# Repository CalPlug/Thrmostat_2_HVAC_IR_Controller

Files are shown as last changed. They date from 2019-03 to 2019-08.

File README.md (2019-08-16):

# ThermostatControl
Jigar Hira

Navid Bazmoon

Code to interface the NEST thermostat with ESP32

Utilizes the RMT ESP32 library to send IR signals controlling a portable AC unit.

## IR Transmission
ESP32 has built-in hardware for handling IR Codes.
The RMT library feeds the hardware two signals:

1)	Data signal which represents the 0 and 1 bits
2)	Carrier frequency square wave

The hardware in the ESP32 modulates the data signal using the square wave to produce the IR signal (more information can be found here: https://docs.espressif.com/projects/esp-idf/en/latest/api-reference/peripherals/rmt.html).

## NEST signals
In order to interface with the NEST smart thermostat, we use a simple circuit to convert 24VAC thermostat signals to lower voltage DC signals.

This allows us to use the GPIO pins on the ESP32 to detect what the NEST has turned on or off.

### NOTE:
This project is still in development

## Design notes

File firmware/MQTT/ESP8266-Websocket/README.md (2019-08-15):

## Modified by Navid Bazmoon - University of California, Irvine

## Changes were made for compatibility with ESP32

The file named MD5.cpp is modified and renamed to MD5ALT.cpp

Also the following changes were made in the above mentioned file:

MD5Init modified to MD5InitALT
MD5Update modified to MD5UpdateALT
MD5Final modified to MD5FinalALT

The file named MD5.h is modified and renamed to MD5ALT.cpp

Also the following changes were made in the above mentioned file:

MD5Init modified to MD5InitALT
MD5Update modified to MD5UpdateALT
MD5Final modified to MD5FinalALT

## End of Comments added by NB

## Websocket Client and Server for ESP-8266

This is a simple library that implements a Websocket client and server running on an ESP-8266.

### Getting started

The example WebSocketServer.html file should be served from any web server you have access to. Remember to change the  URL in it to your Arduino. The examples are based on using a WiFly wireless card to connect. If you're using ethernet instead you'll need to swap out the client class.

Install the library to "libraries" folder in your Arduino sketchbook folder. For example, on a mac that's `~/Documents/Arduino/libraries`.

Try the examples to ensure that things work.

Start playing with your own code!

### Notes
Inside of the WebSocketServer class there is a compiler directive to turn on support for the older "Hixie76" standard. If you don't need it, leave it off as it greatly increases the memory required.

Because of limitations of the current Arduino platform (Uno at the time of this writing), this library does not support messages larger than 65535 characters. In addition, this library only supports single-frame text frames. It currently does not recognize continuation frames, binary frames, or ping/pong frames.

### Credits
Thank you to github user ejeklint for the excellent starting point for this library. From his original Hixie76-only code I was able to add support for RFC 6455 and create the WebSocket client.

- Branden

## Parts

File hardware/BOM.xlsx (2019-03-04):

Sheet: PCB SPECS (please fill in)
PCB
File Name | Material | Layer | Dimension(mm) |  | Quantity (5 min.) | Separated Different Design | Panelized PCBs | Solder Mask Color | Silkscreen Color | PCB Thickness | Copper Thickness | Inner Copper Thickness | Surface Finish
 |  |  | X | Y |  |  |  |  |  | (mm) | (oz) | (oz)
***.ZIP (your Gerber files) | FR-4 TG130 | 2 |  |  | 5 | 1 | Not Required | Green | White | 1.6 | 1 oz | 0.5 oz | HASL (Hot Air Surface Leveling)
SPECIAL REQUIREMENTS
Min. Tracking/Spacing | 6 mil
Min. Hole Size | 0.3 mm
BGA | No
Edge Connector | No
Blind Vias | No
Half Cutted Holes | No
Impedance Control | No
STENCIL
Stencil Dimensions | 190 x 290 mm (frameless)
Stencil Quantity | 1
Fiducial Mark | Yes
Polishing Technique | Polishing
REMARK
Please leave comment here if you have special requirements.

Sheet: BOM (please fill in)
BOM/PCBA quantity (Required)
PCB/Project Name (Required)
Part Identification |  |  |  |  |  |  |  |  | Customer Information |  | Quantity | Remark
# | Part ID / Reference (Required) | Manufacturer | Part Number (Required) | Description | Value (Required) | Package (Required) | THT (y/n) | Pins / Pads Qty | Source/Link/ Datasheet/Note | Source / Target Price | Quantity per BOM (Required)

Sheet: BOM Reference (Example)
BOM/PCBA quantity (Required) |  | 5 | Quantity ordered
PCB/Project Name (Required) |  | AC NEST Integration
Part Identification |  |  |  |  |  |  |  |  | Customer Information |  | Quantity
# | Part ID / Reference (Required) | Manufacturer | Part Number (Required) | Description | Value (Required) | Package (Required) | THT (y/n) | Pins / Pads Qty | Source/Link/ Datasheet/Note | Source / Target Price | Quantity per BOM (Required) | NOTES
1 | A1 | FTDI | FT232RL | IC USB FS SERIAL UART 28-SSOP |  | 28-SSOP | n | 28 | 768-1306-ND https://www.digikey.com/product-detail/en/ftdi-future-technology-devices-international-ltd/FT232RL-TUBE/768-1306-ND/4006920 | 4.50 | 1
2 | A2 | N/A | BUCK CONVERTER | Buck Converter Module |  |  | n | 4 |  |  | 1
3 | A3 | Expressif Systems | ESP32-WROOM-32U | WIFI MODULE 128MBITS SPI FLASH |  |  | n |  | 1904-1028-1-ND https://www.digikey.com/product-detail/en/espressif-systems/ESP32-WROOM-32U-16MB/1904-1028-1-ND/9381737 | 4.50 | 1
4 | A4 | Comchip Technology | DF206ST-G | BRIDGE RECT 1PHASE 600V 2A DFS |  |  | n | 4 | 641-1425-1-ND https://www.digikey.com/product-detail/en/comchip-technology/DF206ST-G/641-1425-1-ND/2208797 | 0.66 | 1
5 | A5, A7, A8 | E-Switch | TL3302AF180QJ | SWITCH TACKTILE SPST-NO 0.05A 12V |  |  | n | 2 | EG4576CT-ND https://www.digikey.com/product-detail/en/e-switch/TL3302AF180QJ/EG4576CT-ND/1786161 | 0.81 | 3
6 | A6 | Toshiba Semiconductor and Storage | TLP290-4 | OPTOISOLTR 2.5KV 4CH TRANS 16-SO |  | 16-SO | n | 16 | TLP290-4(GB-TPE)CT-ND https://www.digikey.com/product-detail/en/toshiba-semiconductor-and-storage/TLP290-4-GB-TPE/TLP290-4-GB-TPE-CT-ND/2754614 | 1.45 | 1
7 | C1, C2, C6, C8 | Samsung | CL10B104KB8NNNC | Capacitor SMD | 0.1uF | 0603 | n | 2 | 1276-1005-1-ND https://www.digikey.com/product-detail/en/samsung-electro-mechanics/CL10B104KO8NNNC/1276-1005-1-ND/3889091 | 0.10 | 4
8 | C2, C7, C9, C10, C11, C12, C13 | Samsung | CL10A105K08NNNC | Capacitor SMD | 10uF | 0603 | n | 2 | 1276-1119-1-ND https://www.digikey.com/product-detail/en/samsung-electro-mechanics/CL10A106MQ8NNNC/1276-1119-1-ND/3889205 | 0.19 | 7
9 | C4, C5 | Murata Electronics North America |  | Capacitor SMD | 47uF | 0603 | n | 2 | 490-13244-1-ND https://www.digikey.com/product-detail/en/murata-electronics-north-america/GRM188C80E476ME05D/490-13244-1-ND/5877452 | 1.82 | 2
10 | D1 | Kingbright | APT1608SGC | Green LED |  | 0603 | n | 2 | 754-1121-1-ND https://www.digikey.com/product-detail/en/kingbright/APT1608SGC/754-1121-1-ND/1747838 | 0.39 | 1
11 | D2 | Kingbright | APT1608EC | Red LED |  | 0603 | n | 2 | 754-1117-1-ND https://www.digikey.com/product-detail/en/kingbright/APT1608EC/754-1117-1-ND/1747834 | 0.37 | 1
12 | J1 | Amphenol ICC (FCI) |  | Micro USB Female SMD |  |  | n | 5 | 609-4613-2-ND https://www.digikey.com/product-detail/en/amphenol-icc-fci/10118192-0001LF/609-4613-1-ND/2785378 | 0.45 | 1
13 | J2, J3, J4, J5 | Phoenix Contact |  | Screw Terminal - 3.5mm - 2 Wire |  |  | y | 2 | 277-1721-ND https://www.digikey.com/product-detail/en/phoenix-contact/1984617/277-1721-ND/950849 | 0.48 | 4
14 | J6, J8, J9 | Harwin Inc. |  | 0.1 in Male THT Headers |  |  | y | 2 to 4 | 952-1902-ND https://www.digikey.com/product-detail/en/harwin-inc/M20-9992046/952-1902-ND/3727869 | 0.63 | 3
15 | R1, R2 |  |  | Resistor SMD | 12K | 603 | n | 2 | RHM12.0KADCT-ND https://www.digikey.com/product-detail/en/rohm-semiconductor/ESR03EZPF1202/RHM12.0KADCT-ND/1983756 | 0.14 | 2
16 | R12, R13, R14, R15, R18, R19, R22, R23 |  |  | Resistor SMD | 1K | 603 | n | 2 | RHM1.0KDCT-ND https://www.digikey.com/product-detail/en/rohm-semiconductor/ESR03EZPJ102/RHM1.0KDCT-ND/1762924 | 0.1 | 8
17 | R7, R8, R16 |  |  | Resistor SMD | 100 | 603 | n | 2 | RHM100DCT-ND https://www.digikey.com/product-detail/en/rohm-semiconductor/ESR03EZPJ101/RHM100DCT-ND/1983776 | 0.1 | 3
18 | R3, R5, R6, R9, R10, R11, R17, R24, R25, R26 |  |  | Resistor SMD | 4.7K | 603 | n | 2 | RHM4.7KDCT-ND https://www.digikey.com/product-detail/en/rohm-semiconductor/ESR03EZPJ472/RHM4.7KDCT-ND/1762936 | 0.1 | 10
19 | R4, R20, R21 |  |  | Resistor SMD | 330 | 603 | n | 2 | RHM330AYCT-ND https://www.digikey.com/product-detail/en/rohm-semiconductor/KTR03EZPF3300/RHM330AYCT-ND/4054158 | 0.16 | 3
20 | T1, T2 | Micro Commercial Co | MMBT3904-TP | NPN Transistor | NPN |  | n | 3 | MMBT3904TPMSCT-ND https://www.digikey.com/product-detail/en/micro-commercial-co/MMBT3904-TP/MMBT3904TPMSCT-ND/717395 | 0.1 | 2

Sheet: Shipping Details (Example)
The shipping information could help us to estimate the shipping cost.
Consignee | Michael Klopfer (Technical) / Alise Adams`(Purchasing)
Company Name | California Plug Load Research Center
Address 1 | 4100 Calit2 Building
Address 2 | UC Irvine
City | Irvine, California
Postcode | 92697
State | California
Country | USA
Telephone Number | 310-502-1971 (Technical Concerns)
Email Address | mklopfer@uci.edu (Technical Concerns) alisea@uci.edu (Billing Concerns)

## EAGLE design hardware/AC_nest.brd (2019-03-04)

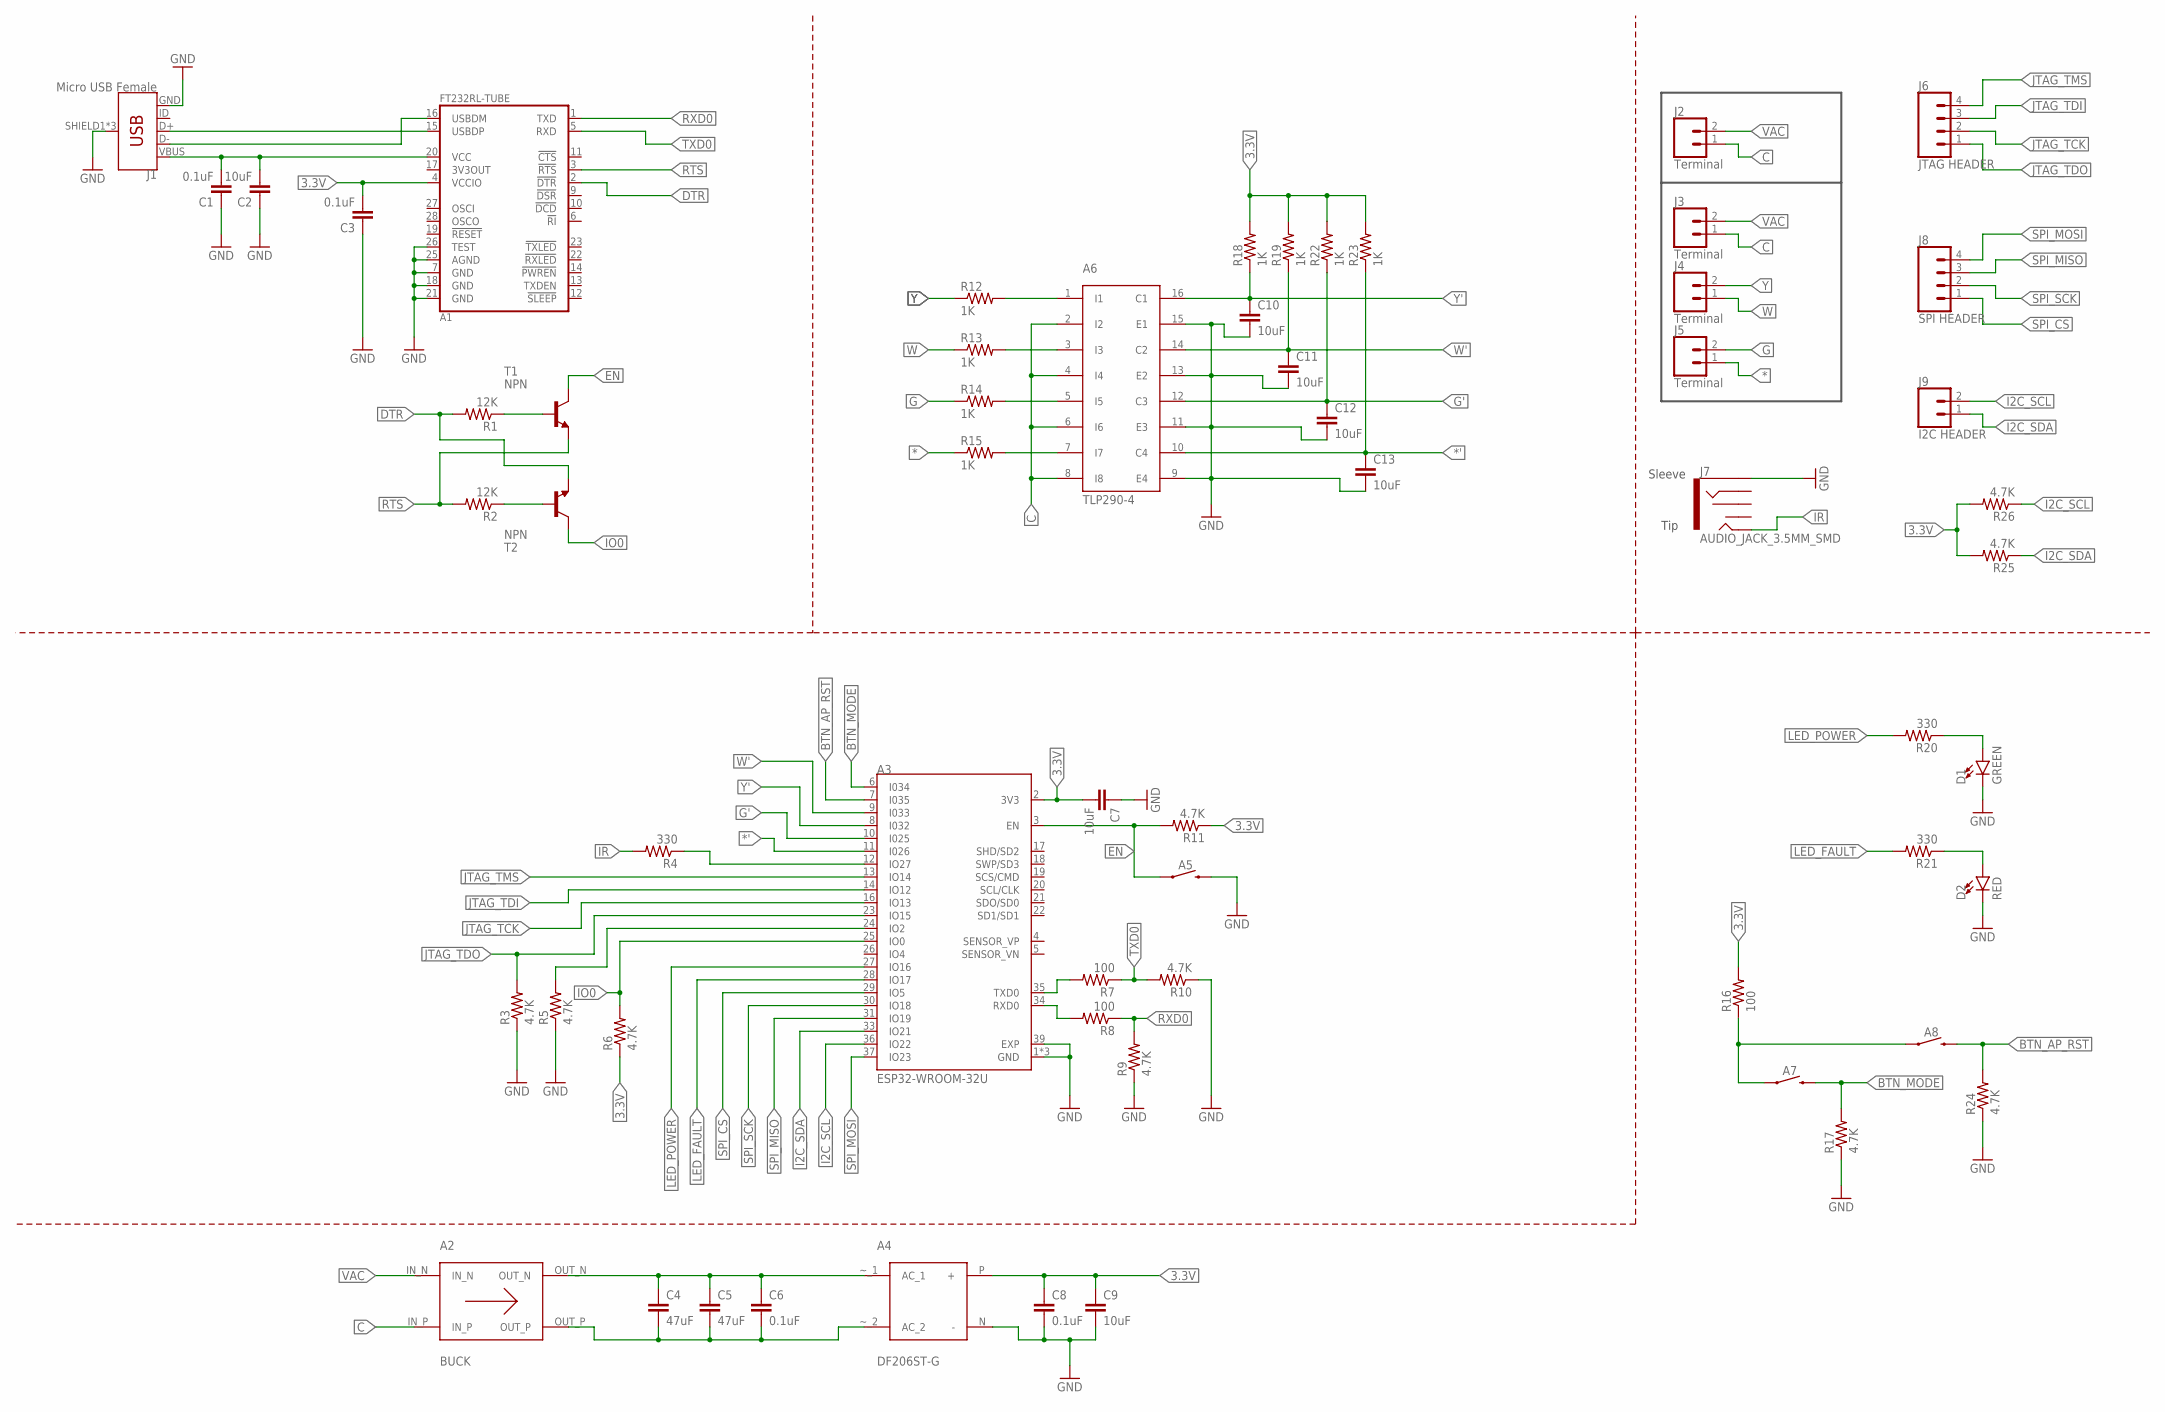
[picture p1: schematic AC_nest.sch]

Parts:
A1: FT232RL; SSOP28-LD
A2: BUCK
A3: ESP32-WROOM-32U; XCVR_ESP32-WROOM-32U
A4: DF206ST-G
A5, A7, A8: TL3302AF180QJ
A6: TLP290-4
C1, C3, C6, C8: 0.1uF; C0603
C2, C7, C9, C10, C11, C12, C13: 10uF; C0603
C4, C5: 47uF; C0603
D1: GREEN; LED-0603
D2: RED; LED-0603
J1: Micro USB Female; USB-B-MICRO-SMD
J2, J3, J4, J5: Terminal; SCREWTERMINAL-3.5MM-2
J6: JTAG HEADER; 1X04
J7: AUDIO_JACK_3.5MM_SMD; AUDIO-JACK-3.5MM-SMD
J8: SPI HEADER; 1X04
J9: I2C HEADER; 1X02
R1, R2: 12K; R0603
R3, R5, R6, R9, R10, R11, R17, R24, R25, R26: 4.7K; R0603
R4, R20, R21: 330; R0603
R7, R8, R16: 100; R0603
R12, R13, R14, R15, R18, R19, R22, R23: 1K; R0603
T1, T2: NPN; SOT23-EBC

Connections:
3.3V: A1.4 (VCCIO), A3.2 (3V3), A4.P (+), C3.2, C7.2, C8.1, C9.1, R6.1, R11.1, R16.2, R18.2, R19.2, R22.2, R23.2, R25.2, R26.2
3V3OUT: A1.17 (3V3OUT)
*: J5.1, R15.1
*': A3.11 (I026), A6.10 (C4), C13.1, R23.1
BTN_AP_RST: A3.7 (I035), A8.2, R24.2
BTN_MODE: A3.6 (I034), A7.2, R17.2
C: A2.IN_P, A6.2 (I2), A6.4 (I4), A6.6 (I6), A6.8 (I8), J2.1, J3.1
DTR: A1.2 (!DTR), R1.2, T2.E
EN: A3.3 (EN), A5.1, R11.2, T1.C
G: J5.2, R14.1
G': A3.10 (I025), A6.12 (C3), C12.1, R22.1
GND: A1.7 (GND), A1.18 (GND), A1.21 (GND), A1.25 (AGND), A1.26 (TEST), A3.1 (GND), A3.15 (GND), A3.38 (GND), A3.39 (EXP), A4.N (-), A5.2, A6.9 (E4), A6.11 (E3), A6.13 (E2), A6.15 (E1), C1.1, C2.1, C3.1, C7.1, C8.2, C9.2, C10.2, C11.2, C12.2, C13.2, D1.C, D2.C, J1.GND, J1.SHIELD1 (SHIELD), J1.SHIELD2 (SHIELD), J1.SHIELD3 (SHIELD), J7.SLEEVE, R3.1, R5.1, R9.1, R10.1, R17.1, R24.1
I2C_SCL: A3.36 (IO22), J9.2, R26.1
I2C_SDA: A3.33 (IO21), J9.1, R25.1
IO0: A3.25 (IO0), R6.2, T2.C
IR: J7.TIP, R4.2
JTAG_TCK: A3.16 (IO13), J6.2
JTAG_TDI: A3.14 (IO12), J6.3
JTAG_TDO: A3.23 (IO15), J6.1, R3.2
JTAG_TMS: A3.13 (IO14), J6.4
LED_FAULT: A3.28 (IO17), R21.2
LED_POWER: A3.27 (IO16), R20.2
unnamed: A6.1 (I1), R12.2
unnamed: A6.3 (I3), R13.2
unnamed: A6.5 (I5), R14.2
unnamed: A6.7 (I7), R15.2
unnamed: A3.34 (RXD0), R8.2
unnamed: A3.24 (IO2), R5.2
unnamed: A3.12 (IO27), R4.1
unnamed: A1.15 (USBDP), J1.D+
unnamed: A3.35 (TXD0), R7.2
unnamed: A1.16 (USBDM), J1.D-
unnamed: A2.OUT_N, A4.~_1 (AC_1), C4.1, C5.1, C6.1
unnamed: R2.1, T2.B
unnamed: A2.OUT_P, A4.~_2 (AC_2), C4.2, C5.2, C6.2
unnamed: R1.1, T1.B
unnamed: D1.A, R20.1
unnamed: D2.A, R21.1
unnamed: A7.1, A8.1, R16.1
RTS: A1.3 (!RTS), R2.2, T1.E
RXD0: A1.1 (TXD), R8.1, R9.2
SPI_CS: A3.29 (IO5), J8.1
SPI_MISO: A3.31 (IO19), J8.3
SPI_MOSI: A3.37 (IO23), J8.4
SPI_SCK: A3.30 (IO18), J8.2
TXD0: A1.5 (RXD), R7.1, R10.2
USB_VBUS: A1.20 (VCC), C1.2, C2.2, J1.VBUS
VAC: A2.IN_N, J2.2, J3.2
W: J4.1, R13.1
W': A3.9 (I033), A6.14 (C2), C11.1, R19.1
Y: J4.2, R12.1
Y': A3.8 (I032), A6.16 (C1), C10.1, R18.1

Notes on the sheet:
Sleeve
Tip

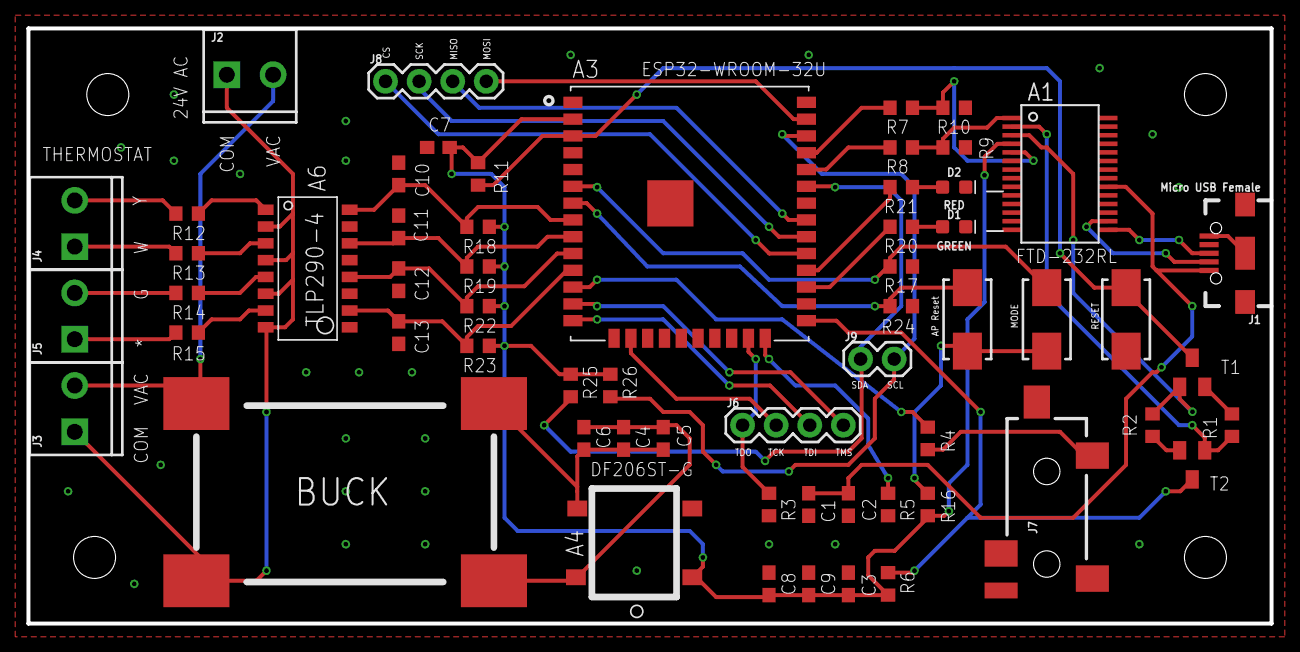
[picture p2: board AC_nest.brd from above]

Board: 2 copper layers, 94.0 x 45.0 mm, 60 parts (0 on the bottom side), 51 nets.

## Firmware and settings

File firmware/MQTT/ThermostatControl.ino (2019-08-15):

/**********************************
* CalPlug Portable AC Integration
* ThermostatControl
* 
* Jigar Hira & Navid Bazmoon 
* Fall 2018
***********************************/

#include "driver/rmt.h" /* ESP32 RMT driver library */

#include "Constants.h"	/* Constants */
#include "Data.h"		/* Data processing */
#include "NESTSignal.h" /* NEST signal handling */
#include "Publish.h"
#include "EPROM.h"
#include "AP.h"

int ISR = 0;  /* Trigger for ISR */

/* Delay variables */
long previousTime = 0;      /* clock tick at previous execution */
unsigned long currentTime;  /* current clock tick */
  

rmt_config_t config;  /* ESP32 RMT configuration */
rmt_item32_t items[LENGTH + 2]  /* RMT send array */;

long long data;  /* data to be sent */

int zero[2] = {ZERO_0, ZERO_1}; /* one and zero burst pairs */   
int one[2] = {ONE_0, ONE_1};

int startMessage[2] = {START_0, START_1};  /* Start message - Does not change between codes */
int endMessage[2] = {END_0, END_1};  /* End message - Does not change between codes */

void setup() {

char epromData[150];
 MQTTsetup ();
 EPROMsetup();
 APsetup(); 
load_data (epromData);  
 if (strstr (epromData, "Default") != NULL){
   
 }
 
  Serial.begin(115200); /* Begin serial monitor */

  /* Input signals from NEST */
  pinMode(AC, INPUT);
  pinMode(HEAT, INPUT);
  pinMode(FAN, INPUT);
  pinMode(HUMIDIFIER, INPUT);

  /* Interrupts */
  attachInterrupt(digitalPinToInterrupt(AC), TriggerISR, CHANGE); /* Sets pin, Interrupt Service Routine (ISR), Trigger */
  attachInterrupt(digitalPinToInterrupt(HEAT), TriggerISR, CHANGE);
  attachInterrupt(digitalPinToInterrupt(FAN), TriggerISR, CHANGE);
  attachInterrupt(digitalPinToInterrupt(HUMIDIFIER), TriggerISR, CHANGE);

  /* ESP32 RMT Configuration Settings */
  config.rmt_mode = RMT_MODE_TX;
  config.channel = RMT_CHANNEL_0;
  config.gpio_num = IR_LED;                                 /* pin on the ESP32 that is being controlled */
  config.mem_block_num = 1;
  config.tx_config.loop_en = 0;
  config.tx_config.carrier_en = 1;                          /* enables carrier signal (modulation) */
  config.tx_config.idle_output_en = 1;
  config.tx_config.idle_level = RMT_IDLE_LEVEL_LOW;         /* default signal is low */
  config.tx_config.carrier_level = RMT_CARRIER_LEVEL_HIGH;  /* data is modulated on the high signals */
  config.tx_config.carrier_duty_percent = 50;               /* carrier duty cyle */
  config.tx_config.carrier_freq_hz = FREQUENCY;             /* frequency of the carrier signal */
  config.clk_div = 80;                                      /* resultion -> ESP32 clock speed is 80MHz so division of 8 gives us 1MHz resolution or 1us per tick */

  rmt_config(&config);  /* Apply RMT configuration settings */
  rmt_driver_install(config.channel, 0, 0); /* install  the ESP32 RMT driver */
  
}

void loop() {

  long long dataForMQTT;  /* Data to send to the MQTT Server */

  if (ISR)
  {
    
    delay(10); /* This is to ensure the digitalRead from the pin is the correct value after the interrupt */
    
    dataForMQTT = SendIR(); /* Generates the IR code and sends the signal */

     publishToMQTT(dataForMQTT);


    ISR = 0;  /* reset ISR variable */     
  }

  currentTime = millis(); /* get the current clock */
  if ((currentTime - previousTime) > POLLRATE)  /* Checks if time interval has passed */
  {
    previousTime = currentTime; /* reset the previous execution time */

    SendIR(); /* Generates the IR code and sends the signal */
    
  }
}


/* Polls the inputs and generates IR command code. Then sends the command via RMT library */
long long SendIR()
{
  /* reads the current input values and generates an IR code to send */
  data = GenerateIRCode(digitalRead(AC), digitalRead(HEAT), digitalRead(FAN), digitalRead(HUMIDIFIER));

  /* Converts the IR binary code to the RMT format and stores the data in (rmt_item32_t) items */
  BinaryToRMT(items, data, LENGTH, startMessage, endMessage, zero, one);

  /* Sends the IR code */
  rmt_write_items(config.channel, items, LENGTH + 2, IRREPEAT);

  Serial.println((int) data, BIN);

  /* Logs to serial monitor */
  Serial.println("Message Sent");

  return data;
}


/* Lightweight ISR to trigger interrupt function */
void TriggerISR()
{
  ISR = 1;  /* ISR global variable */
  
}

/* EOF */

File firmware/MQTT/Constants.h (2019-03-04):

/**********************************
* CalPlug Portable AC Integration
* ESP32 IR Blaster
* 
* Jigar Hira
* Fall 2018
***********************************/

#ifndef _CONSTANTS_
#define _CONSTANTS_


#define LENGTH 40        /* Bit length of the data */
#define POLLRATE 60000   /* NEST signal pollrate and period of IR signals in milliseconds */


/* Pin Definitions */
#define IR_LED        GPIO_NUM_21
#define AC            GPIO_NUM_27
#define HEAT          GPIO_NUM_26
#define FAN           GPIO_NUM_25
#define HUMIDIFIER    GPIO_NUM_33


/* IR CODE SETTINGS */
#define FREQUENCY 38000  /* Frequency in hz of carrier signal*/
#define IRREPEAT 1       /* How many times the IR signal will be repeated (1 means no repetition) */

#define ZERO_0  579       /* timings for binary zero burst pair */
#define ZERO_1  579
#define ONE_0   579       /* timings for binary one burst pair */
#define ONE_1   1632

#define START_0  9079     /* timings for start message burst pair */
#define START_1  4474
#define END_0   579       /* timings for end message burst pair */
#define END_1   32767

/* IR CODES */
#define NUM_OF_BYTES 5  /* number of bytes that make up the IR signal */

#define ADDRESS         0b01001011  /* 1st byte of message */
#define BYTE_3          0b00001110  /* 4th byte of message */
#define BYTE_4          0b00000000  /* 5th byte of message */

/* 2nd byte of the message */
#define MODE_AC         0b01000001
#define MODE_HEAT       0b01000111
#define MODE_FAN        0b01000101
#define MODE_HUMIDIFIER 0b01000011
#define MODE_OFF        0b01000000

/* 3rd byte of the message */
#define TEMP_64         0b00001010  /* 64F which is the lowest setting for the AC */
#define TEMP_64_MEDFAN  0b10001010  /* 64F with the MED fan setting*/
#define TEMP_81         0b00011011  /* 81F which is the highest setting for the heater */


#endif

/* EOF */

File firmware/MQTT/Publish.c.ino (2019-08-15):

/**********************************
* CalPlug Portable AC Integration
* ESP32 Publish to MQTT via WebSocket
* 
* Navid Bazmoon
* Fall 2018
***********************************/


#include "Publish.h"
#include <WiFi.h>
#include <WebSocketClient.h>
#include <PubSubClient.h>

//MQTT Credentials 
const char* userName = "Naviiid";
const char* passwordPub =  "12345678";
const char* mqttServer = "m10.cloudmqtt.com";
const int mqttPort = 17934;
const char* mqttUser = "dkpljrty";
const char* mqttpasswordPub = "ZJDsxMVKRjoR";


//Websocket Credentials 
char path[] = "/echo";
char host[] = "demos.kaazing.com";

WebSocketClient webSocketClient;

WiFiClient ESP32Client;
WiFiClient clientW;
PubSubClient client(ESP32Client);


 
void MQTTsetup() {
   
  WiFi.begin(userName, passwordPub);
 
  while (WiFi.status() != WL_CONNECTED) {
    
    delay(500);
    Serial.println("Connecting to WiFi Network......");
    
  }
 
  Serial.println("Nice! Connected to the WiFi network.");
 
  client.setServer(mqttServer, mqttPort);
 
  while (!client.connected()) {
    Serial.println("Connecting to MQTT Server.......");
 
    if (client.connect("ESP32Client", mqttUser, mqttpasswordPub )) {
 
      Serial.println("Your are now connected to mqtt.");
 
    } else {
 
      Serial.print("Sorry! The connection failed !");
      Serial.print(client.state());
      delay(2000);
    }

    
  }

  if (clientW.connect(host, 80)) {
    Serial.println("Connected");
  } else {
    Serial.println("Connection failed.");
  }

  publishToMQTT( 1);
  
  webSocketClient.path = path;
  webSocketClient.host = host;
  if (webSocketClient.handshake(clientW)) {
    Serial.println("Handshake successful");
  } else {
    Serial.println("Handshake failed.");
  }
  
 }


 void publishToMQTT(long long dataSet) //make sure to do anclient connected check before calling!
 {
    // To write multiple fields for MQTT Posting
   char payload[255];
   
  snprintf(payload, sizeof(payload), "%lld", dataSet);
for (int i=0; i<10; i++) {  client.publish("esp/test", "This is a test !");
                            }
}

/*
void loop() {

  String data;

  client.loop(); 
   
  if (client.connected()) {
 
    webSocketClient.sendData("Information Sent: Information is sent and will be echoed back");
 
    webSocketClient.getData(data);
    if (data.length() > 0) {
      Serial.print("Received data: ");
      Serial.println(data);
    }
 
  } else {
    Serial.println("Client disconnected.");
  }
 
  delay(3000);
 
}
*/

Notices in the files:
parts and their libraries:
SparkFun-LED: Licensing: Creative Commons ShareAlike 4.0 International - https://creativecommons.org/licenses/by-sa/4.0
